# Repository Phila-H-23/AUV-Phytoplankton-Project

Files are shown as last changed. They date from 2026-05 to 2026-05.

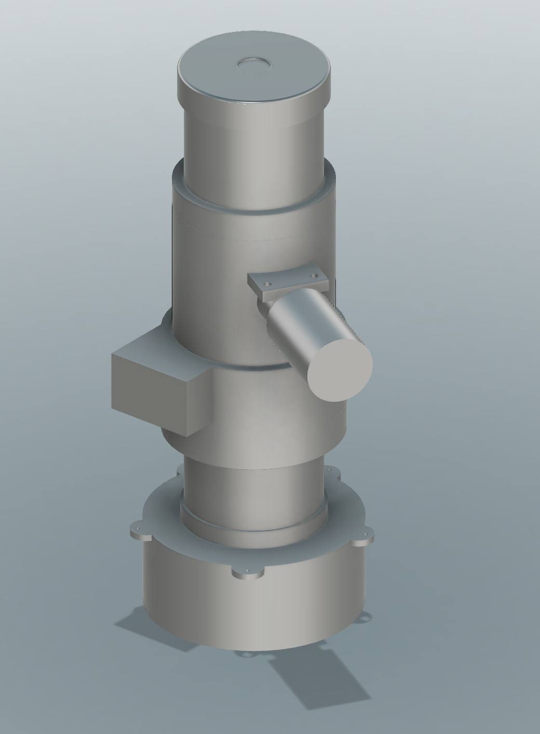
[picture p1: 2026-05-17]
Housing Design/renders/full_sys_design.png

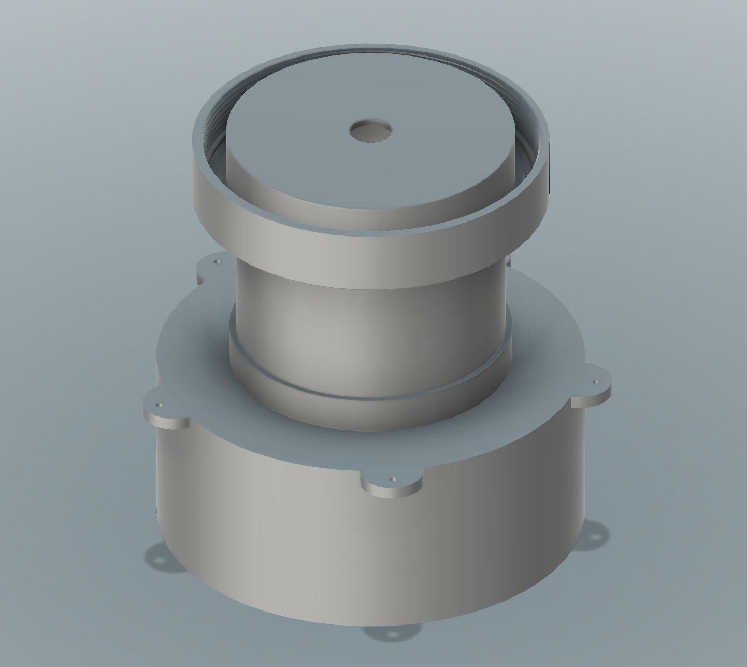
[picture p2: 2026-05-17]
Housing Design/renders/external_cylinder.png

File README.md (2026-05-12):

# AUV-Phytoplankton-project

## EEE4113F Group Project — University of Cape Town

An autonomous underwater vehicle (AUV) designed for vertical water column profiling and phytoplankton concentration measurement. The vehicle uses a buoyancy-driven mechanism to control depth, making it quiet, energy-efficient, and minimally disruptive to the surrounding marine environment.

## Project overview
Phytoplankton play a critical role in marine ecosystems and are sensitive indicators of ocean health. This AUV autonomously profiles the water column, measuring phytoplankton concentration at varying depths without external control or propulsion. By using buoyancy rather than thrusters, the vehicle avoids disturbing the water column during measurement — improving data quality and reducing power consumption.

# Repository structure
```
AUV-Phytoplankton-Project/
│
├── Depth Controller/       # Control system design and firmware
├── Actuator Design/        # Buoyancy actuator design and 3D models
├── Housing Design/         # Pressure housing design and 3D models
└── Power/                  # Power electronics and electrical systems
```

# Subsystems
### 🎛️ Depth controller
The depth control subsystem is responsible for autonomously regulating the vehicle's depth during a dive profile. It processes sensor data and drives the buoyancy actuator to track target depth setpoints.

### ⚙️ Actuator design
The buoyancy actuator controls the vehicle's depth by varying its displaced volume. A syringe mechanism draws in or expels water to make the vehicle sink or rise, with 3D-printed components designed for reliable underwater operation.

### 🏠 Housing design
The pressure housing provides a watertight enclosure for all onboard electronics. It is designed to withstand hydrostatic pressure during dives while remaining compact and manufacturable using available fabrication methods.

### 🔋 Power
The power subsystem is responsible for all electrical power on the vehicle. This includes battery selection and charging, power distribution to all subsystems, motor drive circuitry, voltage regulation for the microcontroller and sensors, and the design of supporting circuits such as switching circuits and protection electronics.

## Getting started
Each subsystem folder contains its own documentation. Refer to the individual folders for design files, source code, and setup instructions specific to each subsystem.

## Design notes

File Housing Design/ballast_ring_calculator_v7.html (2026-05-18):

# Ballast Ring Calculator

EEE4113F // Group 1 // 2026

Float: Ø120 mm · System mass (no ring): ~1,630 g (PLA 15% infill) · sensors included · ID fixed at Ø126 mm

Ring geometry

Inner diameter (ID)126 mm (fixed)

Fits over ext. cylinder OD (120 mm) + 3 mm wall clearance.

Outer diameter (OD)160 mm

Ring wall = (OD − ID) / 2

Ring height h20 mm

Number stacked1

Stack identical rings at the bottom for more mass.

Weight mode

Solid ring Loose hardware Bolts + sand

Material

Corrosion-resistant, seawater-safe. Recommended.

Bolts screwed symmetrically on PCD (midpoint of ID and OD). Count calculated from how many fit.

Hardware material

Bolt/nut size

Rows of bolts (axial)1

PCD: — mm · Bolts/row: — · Total: —
Per bolt: — g · Total mass: — g

Fixed: 1 pack M10×100 bolts (10 bolts, ~720 g) on PCD. Remaining groove filled with sand (ρ = 1,920 kg/m³). Groove height = ring height × rings stacked (set above).

Groove vol: — cm³ · Bolts displace: — cm³
Sand vol: — cm³ · Sand mass: — g
Bolt mass (fixed): 720 g · Total: — g

Zone heights

Top cap + electronicsmm

Sensor + actuator zonemm

External cylindermm

Total height | 528 mm
Float diameter | 120 mm (fixed)
Piston stroke | 164.4 mm
Swept volume | 1,832 mL
Total displacement | 6,865 mL

Piston state

Extended (float) Retracted (sink)

Sensor mass

With sensors Without sensors

ECO: 400g · TRN100: 35g · GNSS: 2.75g = 437.75g

Ring mass

—g

Net buoyancy

—N

CB−CM sep.

—%L

CM from bottom

—mm

Ring volume

—cm³

Wall thickness

—mm

Equilibrium pos.

—mm

Eq. (% stroke)

—%

Water at eq.

—mL

Cross-section — to scale (vertical)

—

Calculations

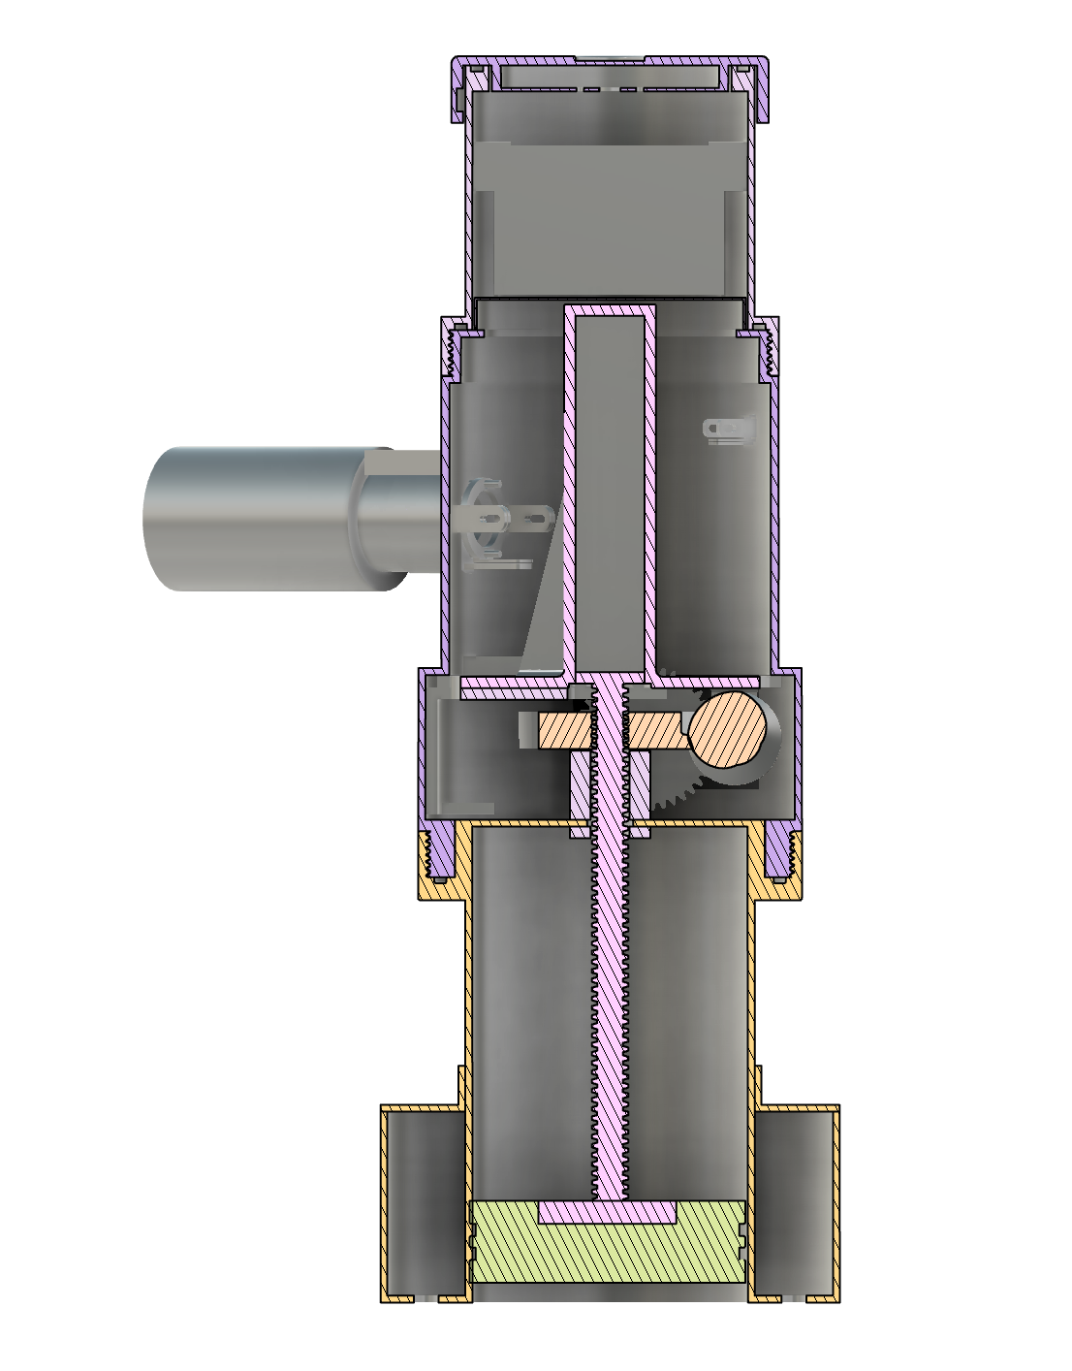
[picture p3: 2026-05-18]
Housing Design/renders/front.png

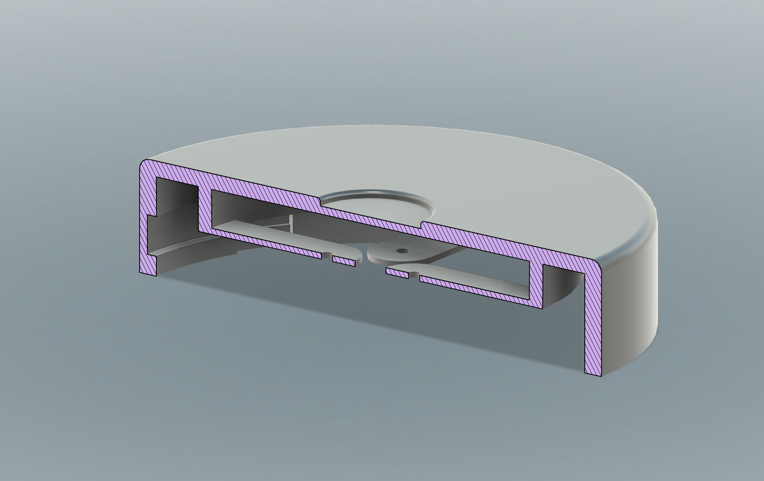
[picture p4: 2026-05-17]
Housing Design/renders/top_cap_section.png

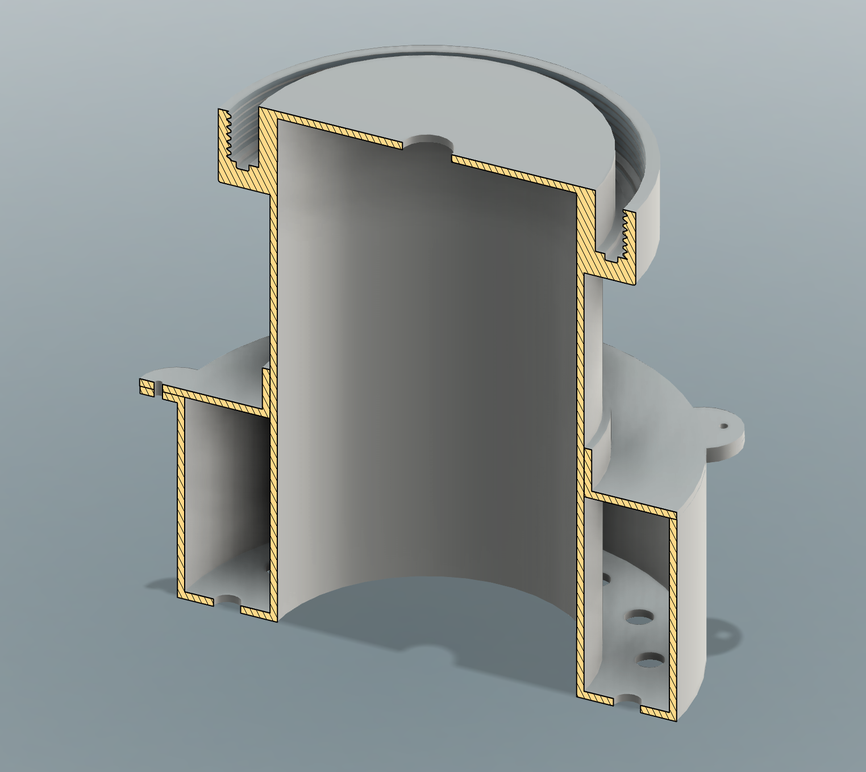
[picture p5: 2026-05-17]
Housing Design/renders/external_cylinder_section.png

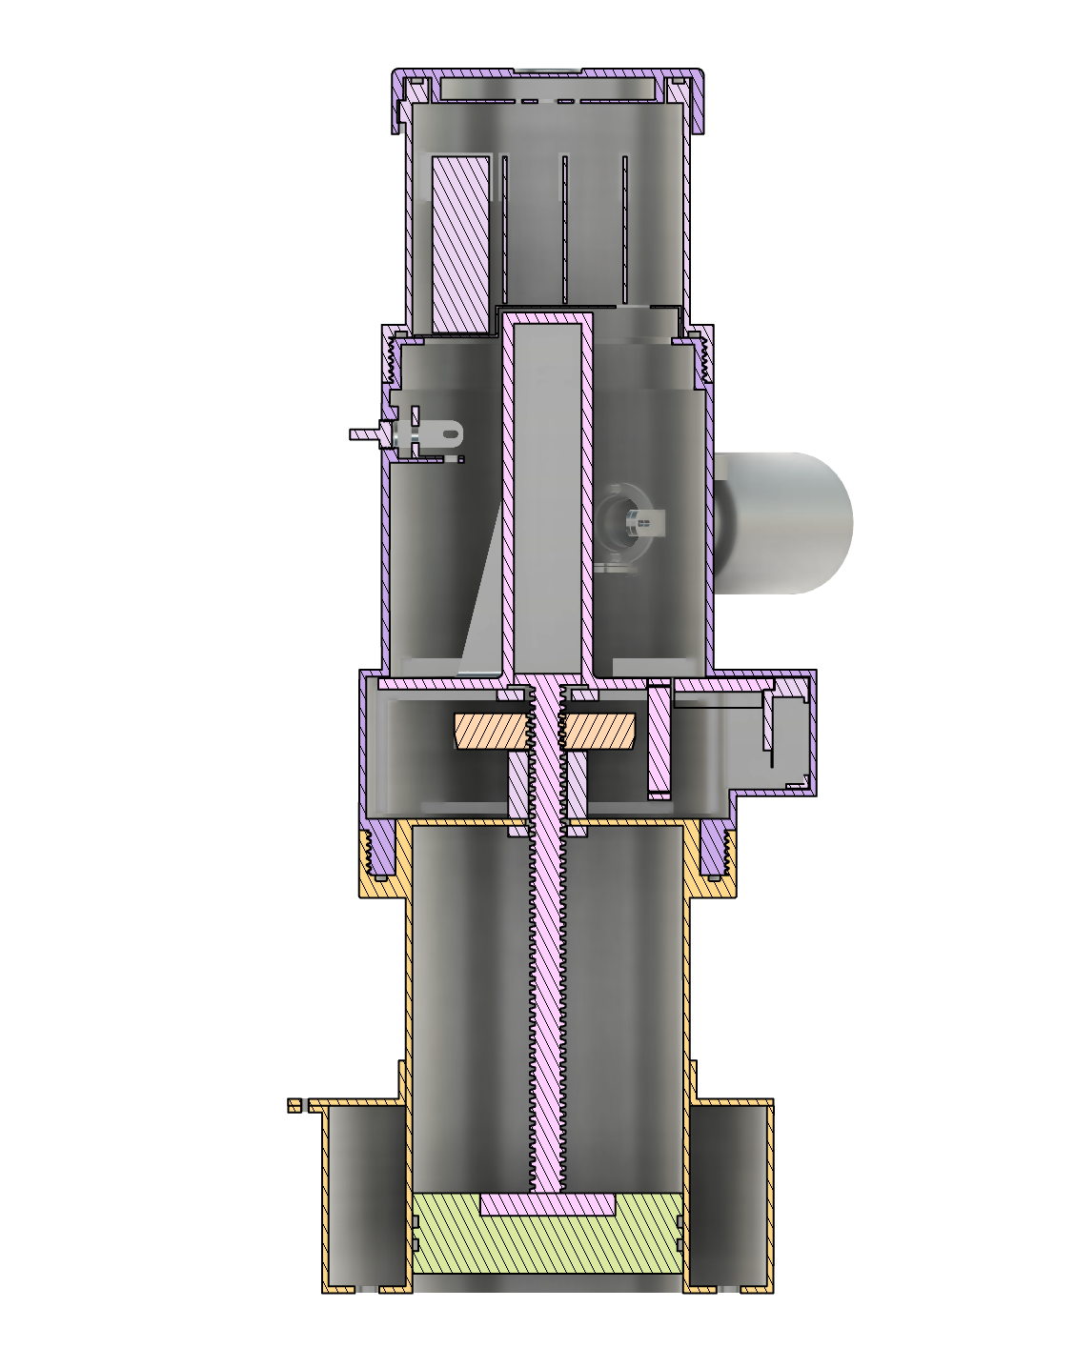
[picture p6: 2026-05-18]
Housing Design/renders/right.png

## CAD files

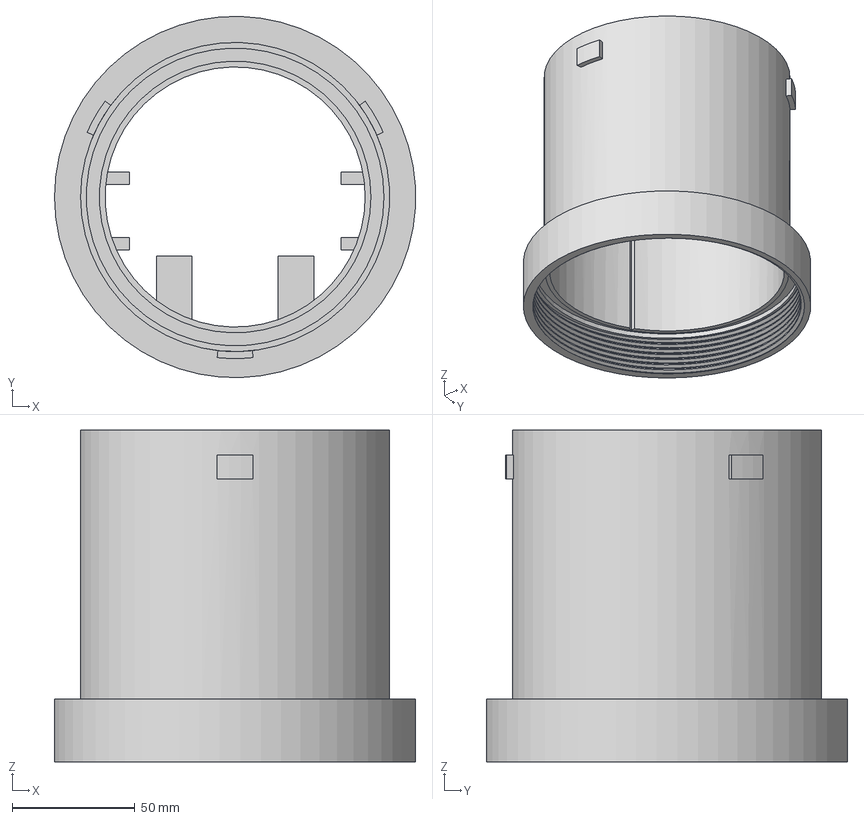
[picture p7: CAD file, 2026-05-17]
Housing Design/system components - step files/electronics tube.step
146.9 x 146.9 x 135.0 mm

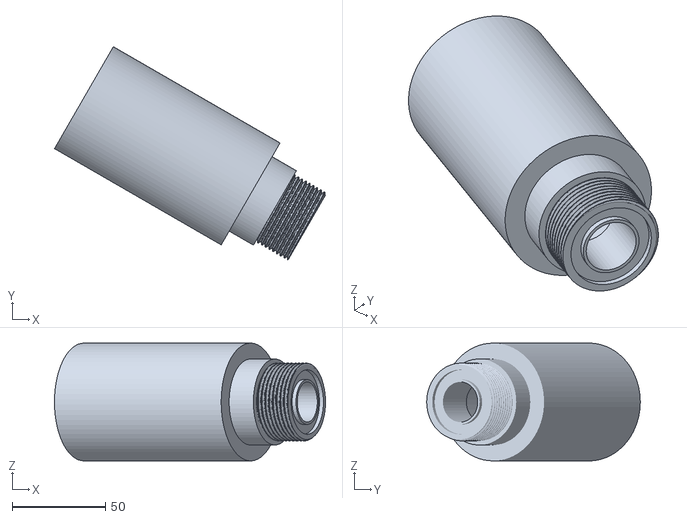
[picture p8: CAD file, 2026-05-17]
Housing Design/system components - stl files/mock eco flntu - model.stl
145.0 x 114.3 x 63.0

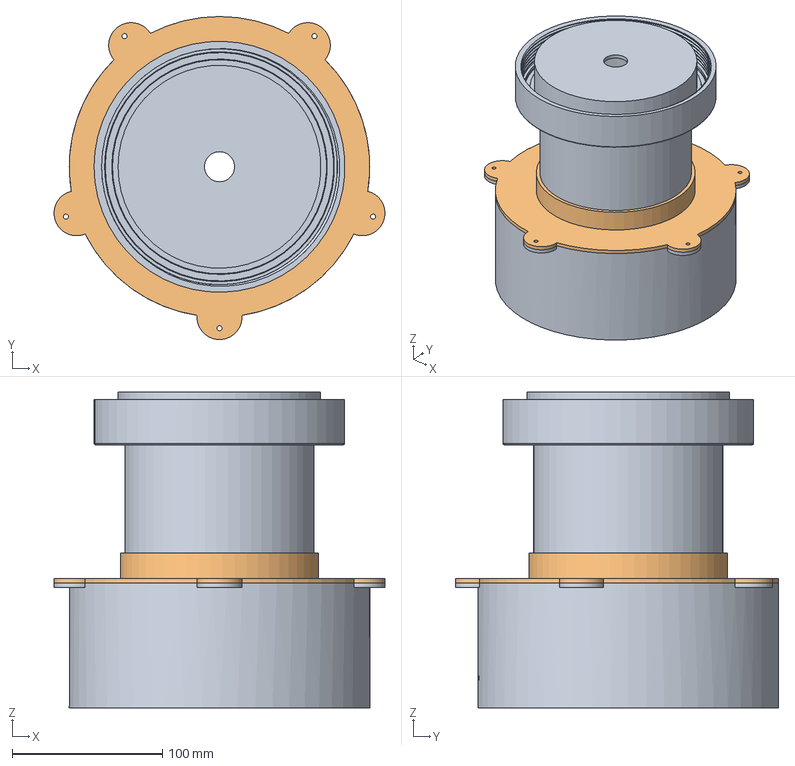
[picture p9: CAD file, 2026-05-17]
Housing Design/system components - step files/external cylinder.step
220.2 x 215.0 x 210.0 mm

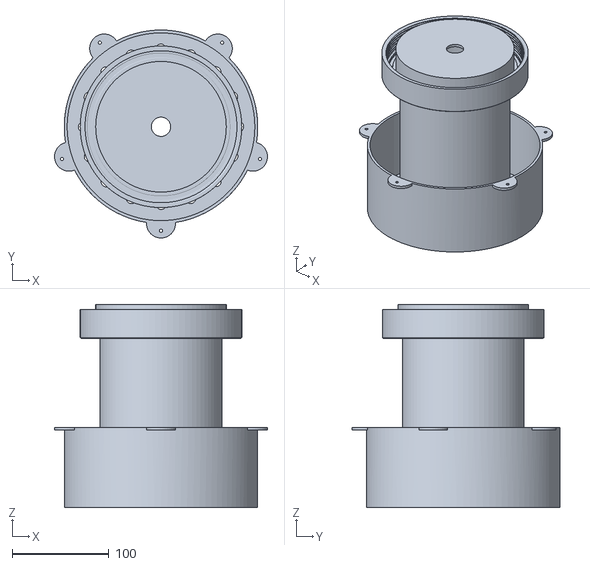
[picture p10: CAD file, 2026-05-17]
Housing Design/system components - stl files/external cylinder - model.stl
220.2 x 214.9 x 210.0

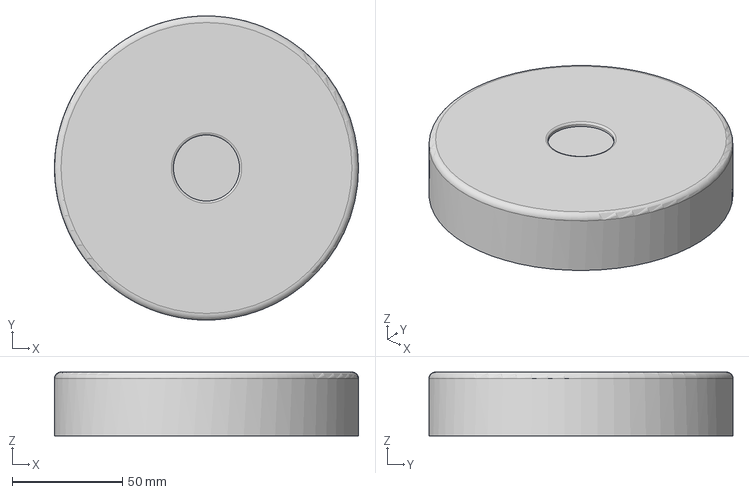
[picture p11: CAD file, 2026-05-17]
Housing Design/system components - step files/top cap.step
138.0 x 138.0 x 29.0 mm

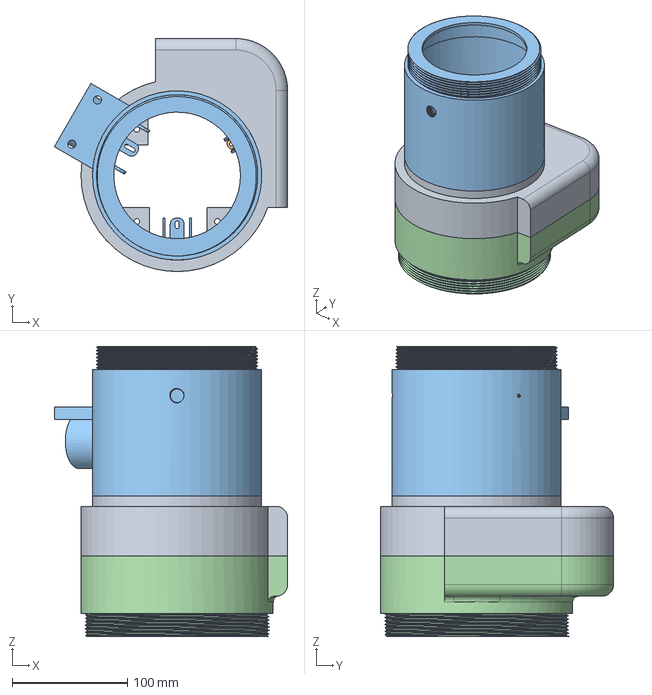
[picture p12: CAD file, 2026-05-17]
Housing Design/system components - step files/sensor-actuator zone.step
202.7 x 202.5 x 252.0 mm

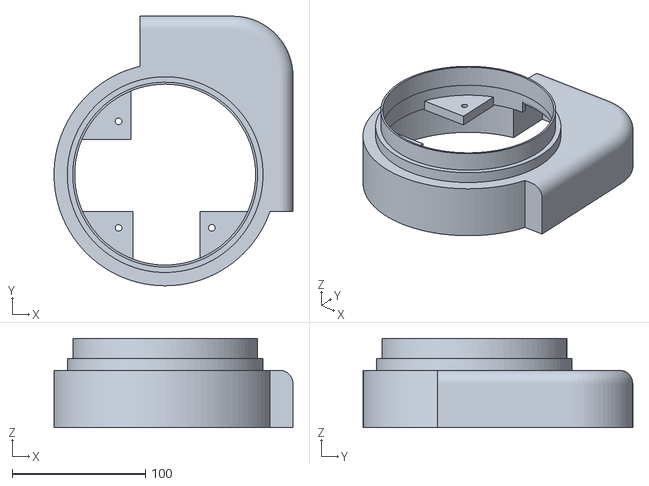
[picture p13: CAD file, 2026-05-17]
Housing Design/system components - stl files/sensor-actuator zone MIDDLE - model.stl
179.5 x 202.5 x 66.9

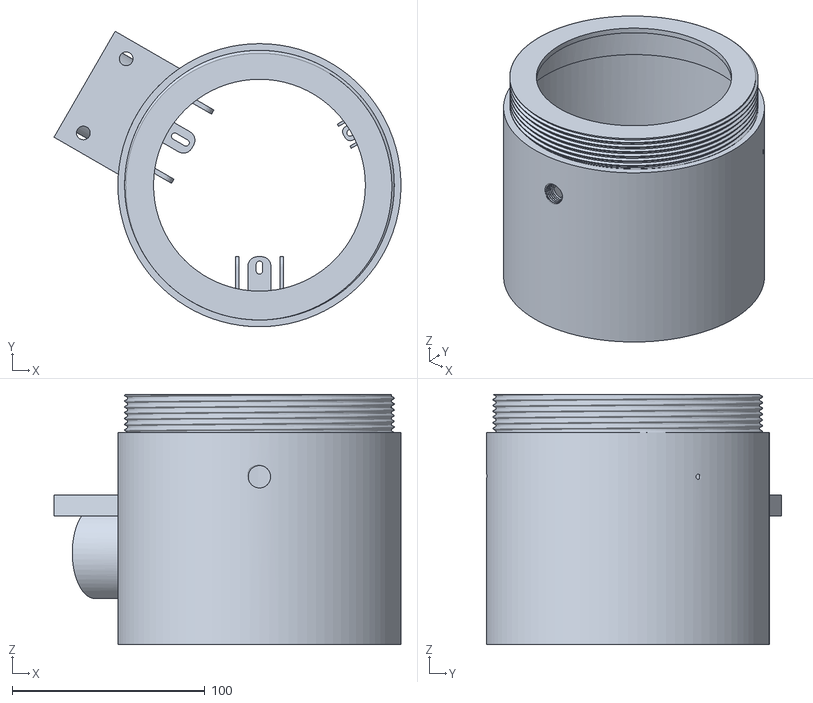
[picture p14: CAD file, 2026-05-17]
Housing Design/system components - stl files/sensor-actuator zone TOP - model.stl
180.2 x 153.4 x 130.0

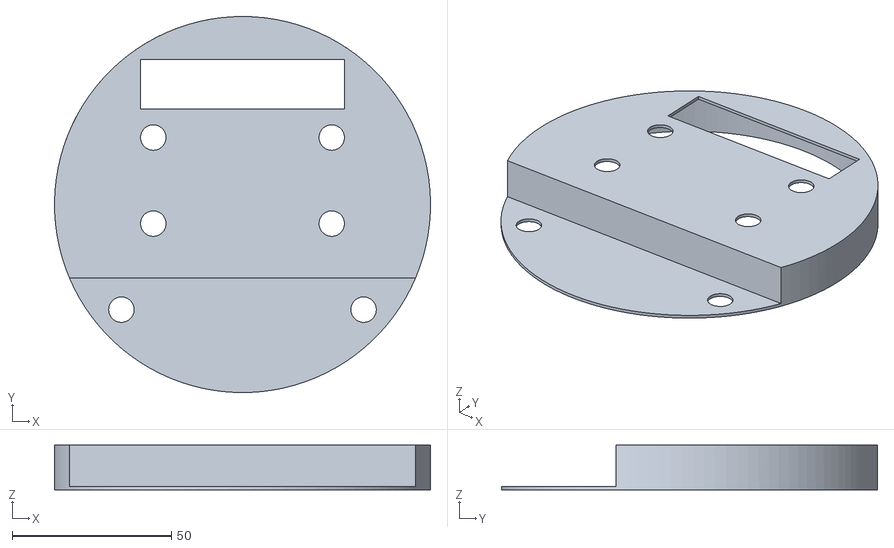
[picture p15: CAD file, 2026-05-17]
Housing Design/system components - stl files/electronics balancer - model.stl
118.0 x 118.0 x 14.0

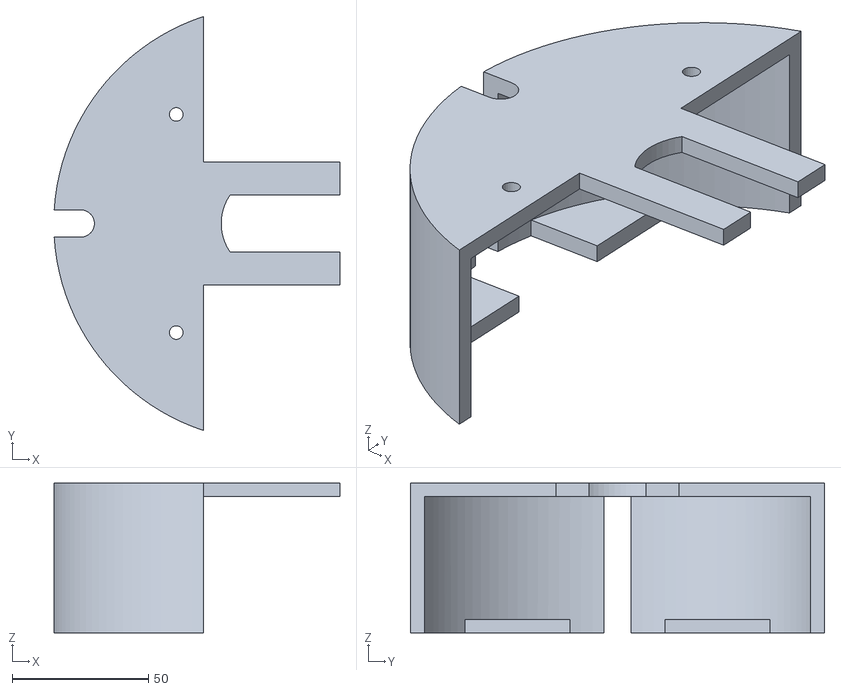
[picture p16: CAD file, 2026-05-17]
Housing Design/system components - stl files/guide cylinder fastener - model.stl
104.8 x 151.8 x 55.0

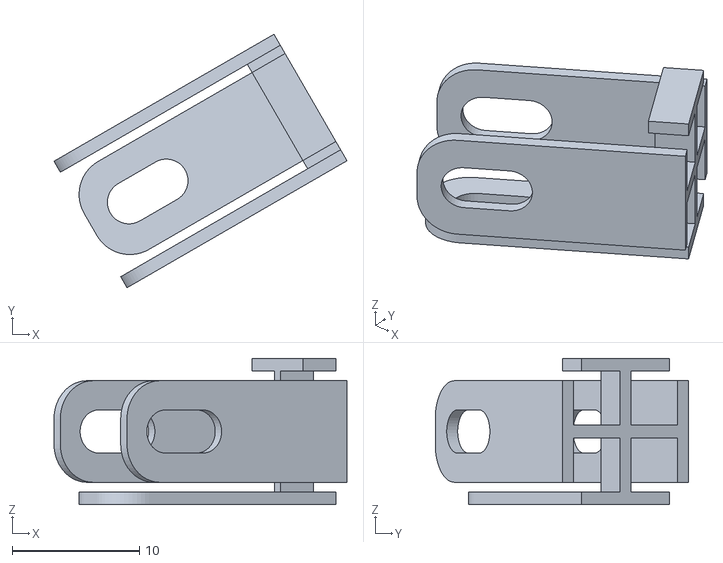
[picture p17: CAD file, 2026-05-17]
Housing Design/system components - stl files/depth sensor fastener - model.stl
23.1 x 20.0 x 11.5

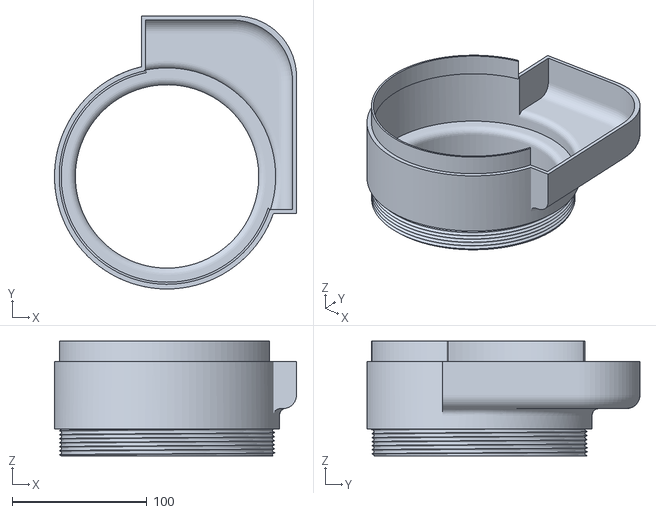
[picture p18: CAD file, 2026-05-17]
Housing Design/system components - stl files/sensor-actuator zone BOTTOM - model.stl
179.5 x 202.5 x 85.0

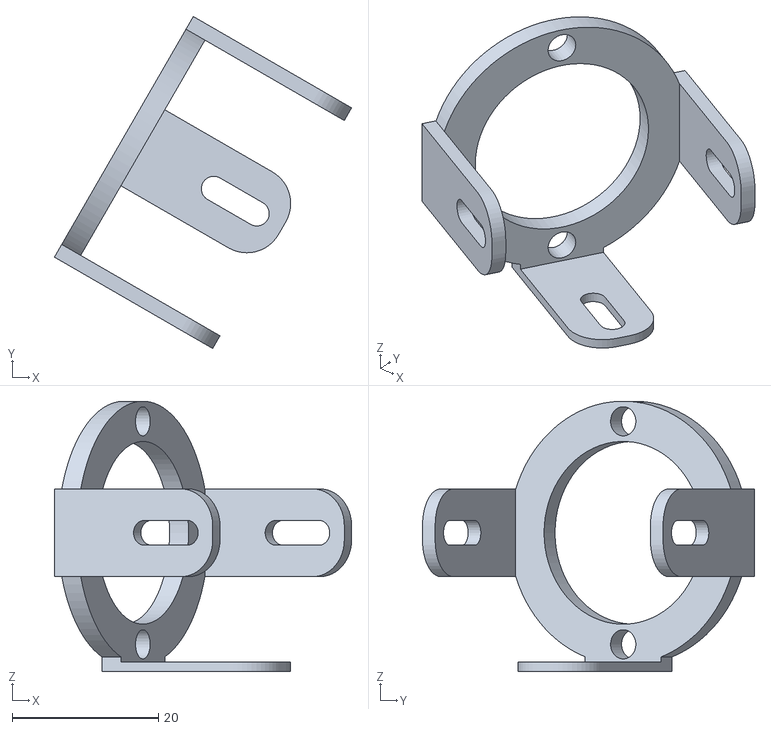
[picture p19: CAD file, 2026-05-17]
Housing Design/system components - stl files/eco flntu fastener - model.stl
40.7 x 45.4 x 37.0

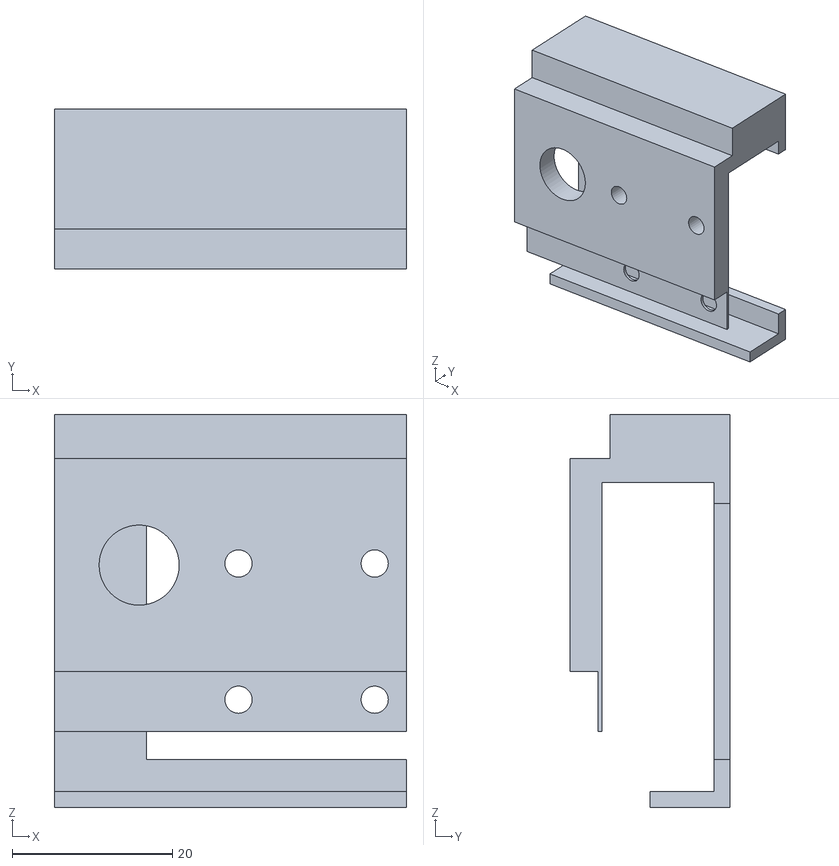
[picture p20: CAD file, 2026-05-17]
Housing Design/system components - stl files/angle sensor mount - model.stl
44.0 x 20.0 x 49.1

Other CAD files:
Housing Design/system components - stl files/electronics tube - model.stl
Housing Design/system components - stl files/service cap - model.stl
Housing Design/system components - stl files/weight lid - model.stl
Housing Design/system components - stl files/temp sensor fastener - model.stl
Actuator Design/Gears.f3d
Actuator Design/Guide_Stand.f3d
Actuator Design/Lead Screw Head.f3d
Actuator Design/Lead Screw.f3d
Actuator Design/Motor.f3d
Actuator Design/Piston head.f3d
Actuator Design/Radial Bearing Stand.f3d
Actuator Design/Thrust Bearing Worm.f3d

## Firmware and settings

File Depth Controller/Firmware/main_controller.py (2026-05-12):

# ================================================================
# main_controller.py
# MicroPython -- Raspberry Pi Pico
# Cascaded depth controller for buoyancy-driven UUV
#
# Architecture:
#   Outer loop: MS5837 depth feedback -> shaft velocity reference
#   Inner loop: AS5600 shaft velocity feedback -> motor voltage
#
# Physical behaviour:
#   Piston retracts (shaft_pos increases) -> water fills chamber
#                                         -> vehicle gets heavier
#                                         -> vehicle sinks (depth increases)
#   Piston extends  (shaft_pos decreases) -> water leaves chamber
#                                         -> vehicle gets lighter
#                                         -> vehicle rises  (depth decreases)
#
# Constraints enforced:
#   1. Stroke limits   -- piston cannot travel beyond 0-16.2cm
#   2. Velocity limit  -- shaft velocity capped at 14.73 mm/s (physical max)
#   3. Current limit   -- voltage clamped to +/-2.142V (3A x Ra) at two points
#   4. Depth fault     -- latching stop if depth exceeds DEPTH_MAX_OP
#   5. Stroke fault    -- latching stop if encoder exceeds stroke limit
#
# Startup sequence (order is critical):
#   1. Ensure piston is fully extended (maximum buoyancy, vehicle at surface)
#   2. Run check_magnet()  -- confirm AS5600 has valid magnet signal
#   3. Run encoder.calibrate() -- set position zero at fully extended position
#   4. Run depth_s.calibrate() -- record atmospheric pressure before water entry
#   5. Set TARGET_DEPTH and run
# ================================================================
 
from machine import I2C, Pin
import time
 
from sensor_interface import AS5600, MS5837
from motor_driver import BTS7960
from parameters import (Ks, Ts, V_SAFE_MAX, V_SAFE_MIN,
                        NUM_INNER, DEN_INNER, K_OUTER, K_D,
                        ALPHA_VEL,ALPHA_DR, STROKE_MAX, STROKE_MIN,
                        MAX_STROKE_VELOCITY, STROKE_EQUILIBRIUM,
                        DEPTH_MIN_OP, DEPTH_MAX_OP)
 
# ================================================================
# HARDWARE INITIALISATION
# I2C bus 0: SDA=GP4 (pin 6), SCL=GP5 (pin 7), 400kHz
# Both AS5600 (0x36) and MS5837 (0x76) share this bus
# ================================================================
i2c     = I2C(0, sda=Pin(4), scl=Pin(5), freq=400_000)
encoder = AS5600(i2c, Ks, ALPHA_VEL)
depth_s = MS5837(i2c, fluid_density=1025.0)    # seawater: 1025, fresh: 1000
motor   = BTS7960(v_supply=12.0)
 
# ================================================================
# STARTUP CALIBRATION SEQUENCE
# ================================================================
print("\n--- Startup sequence ---")
print("Ensure piston is FULLY EXTENDED before continuing")
print("(maximum buoyancy -- vehicle should float at surface)")
 
encoder.check_magnet()     # verify AS5600 magnet signal is valid
encoder.calibrate()        # zero shaft position at fully extended
depth_s.calibrate()        # record surface pressure before water entry
 
print(f"\nEquilibrium stroke position: {STROKE_EQUILIBRIUM*100:.1f} cm")
print(f"Control authority: +/-{STROKE_EQUILIBRIUM*100:.1f} cm from equilibrium")
print("Calibration complete\n")
 
# ================================================================
# MISSION SETPOINT
# Change TARGET_DEPTH to set the desired operating depth [m]
# For first hardware test use a small value (e.g. 0.2m)
# ================================================================
TARGET_DEPTH = 0.2          # m -- START SMALL for first test
 
# ================================================================
# CONTROLLER STATE
# Two samples of memory needed for the second-order difference equation
# Must be reset to zero at startup (or on mission restart)
# ================================================================
e_prev1 = 0.0   # inner loop error: e[k-1]
e_prev2 = 0.0   # inner loop error: e[k-2]
u_prev1 = 0.0   # inner loop output: u[k-1]
u_prev2 = 0.0   # inner loop output: u[k-2]
depth_prev = 0.0    # for derivative term on depth rate
depth_rate_filt  = 0.0   # low-pass filtered depth rate (2 rad/s cutoff)
# ================================================================
# FAULT FLAG
# Latches True on any safety limit violation
# Motor stops and stays stopped until power cycle
# ================================================================
FAULT = False
 
# ================================================================
# CONTROL STEP FUNCTION
# Implements one iteration of the cascaded controller
# Called every Ts=0.005s (200Hz) from the main loop
# ================================================================
def control_step(target_depth, meas_depth, shaft_pos, shaft_vel):
    """
    One 200Hz iteration of the cascaded depth controller.
 
    Outer loop (slow, 1.0 rad/s bandwidth):
        Computes how fast the piston should move based on depth error.
        Positive depth error (too shallow) -> positive shaft_vel_ref (retract)
        Negative depth error (too deep)    -> negative shaft_vel_ref (extend)
 
    Inner loop (fast, 21.5 rad/s bandwidth):
        Tracks the velocity reference from the outer loop.
        Implements the discrete lead-integrator compensator.
        Outputs a voltage command to the motor driver.
 
    Constraints applied (in order):
        1. Stroke limits  -- zero velocity reference at physical endpoints
        2. Velocity limit -- cap shaft velocity to physical maximum
        3. Current limit  -- clamp voltage to +/-V_SAFE_MAX
 
    Args:
        target_depth : float -- desired depth setpoint [m]
        meas_depth   : float -- current depth from MS5837 [m]
        shaft_pos    : float -- current piston position from AS5600 [m]
        shaft_vel    : float -- current piston velocity from AS5600 [m/s]
 
    Returns:
        voltage      : float -- motor voltage command [V]
        shaft_vel_ref: float -- velocity reference sent to inner loop [m/s]
    """
    global e_prev1, e_prev2, u_prev1, u_prev2, depth_prev, depth_rate_filt

    # ---- Depth rate estimate: differentiate then low-pass filter ----
    # Raw differentiation at 200Hz amplifies MS5837 noise severely.
    # ALPHA_DR = exp(-2 * Ts) = 0.9900 gives 2 rad/s cutoff --
    # fast enough to track real depth changes, slow enough to reject noise.
    depth_rate_raw  = (meas_depth - depth_prev) / Ts
    depth_rate_filt = ALPHA_DR * depth_rate_filt \
                    + (1.0 - ALPHA_DR) * depth_rate_raw
    depth_prev      = meas_depth

    # ---- Outer loop: PD on depth ----------------------------
    # K_OUTER = 0.1  proportional -- drives toward target
    # K_D     = 4.3  derivative   -- brakes approach, prevents overshoot
    depth_error   = target_depth - meas_depth
    shaft_vel_ref = K_OUTER * depth_error - K_D * depth_rate_filt

    # ---- Stroke limits --------------------------------------
    if shaft_pos >= STROKE_MAX and shaft_vel_ref > 0:
        shaft_vel_ref = 0.0
    if shaft_pos <= STROKE_MIN and shaft_vel_ref < 0:
        shaft_vel_ref = 0.0

    # ---- Velocity ceiling -----------------------------------
    shaft_vel_ref = max(-MAX_STROKE_VELOCITY,
                        min( MAX_STROKE_VELOCITY, shaft_vel_ref))

    # ---- Inner loop difference equation --------------------
    e_k = shaft_vel_ref - shaft_vel
    u_k = (DEN_INNER[0] * u_prev1
         + DEN_INNER[1] * u_prev2
         + NUM_INNER[0] * e_k
         + NUM_INNER[1] * e_prev1
         + NUM_INNER[2] * e_prev2)

    # ---- Current limit -------------------------------------
    u_k = max(V_SAFE_MIN, min(V_SAFE_MAX, u_k))

    # ---- Shift memory --------------------------------------
    e_prev2 = e_prev1;  e_prev1 = e_k
    u_prev2 = u_prev1;  u_prev1 = u_k
    return u_k, shaft_vel_ref
 
# ================================================================
# MAIN CONTROL LOOP
# ================================================================
print(f"Controller running")
print(f"  Target depth:      {TARGET_DEPTH} m")
print(f"  Max piston vel:    {MAX_STROKE_VELOCITY*1000:.2f} mm/s")
print(f"  Voltage ceiling:   +/-{V_SAFE_MAX:.4f} V")
print(f"  Sample rate:       {1/Ts:.0f} Hz")
print(f"  Depth fault limit: {DEPTH_MAX_OP} m")
print()
 
loop_count = 0
 
try:
    while not FAULT:
        t0 = time.ticks_ms()
 
        # ---- Read sensors -----------------------------------
        meas_depth = depth_s.read_depth()       # [m] from MS5837
        shaft_pos  = encoder.read_position()    # [m] from AS5600
        shaft_vel  = encoder.read_velocity(Ts)  # [m/s] differentiated + filtered
 
        # ---- Safety fault checks (latching) -----------------
        # Depth fault: vehicle has gone too deep
        if meas_depth > DEPTH_MAX_OP:
            print(f"FAULT: depth {meas_depth:.3f}m exceeds limit {DEPTH_MAX_OP}m")
            FAULT = True
            break
 
        # Stroke fault: encoder reading beyond physical travel
        # 5% tolerance accounts for sensor noise near the endpoint
        if shaft_pos > STROKE_MAX * 1.05:
            print(f"FAULT: shaft {shaft_pos*100:.2f}cm exceeds stroke {STROKE_MAX*100:.1f}cm")
            FAULT = True
            break
 
        # ---- Run cascaded controller ------------------------
        voltage, shaft_vel_ref = control_step(
            TARGET_DEPTH, meas_depth, shaft_pos, shaft_vel)
 
        # ---- Drive motor ------------------------------------
        motor.set_voltage(voltage)
 
        # ---- Log every 10 loops (20Hz printout) -------------
        if loop_count % 10 == 0:
            depth_err  = TARGET_DEPTH - meas_depth
            stroke_pct = (shaft_pos / STROKE_MAX) * 100
 
            # Show direction the controller is commanding
            if shaft_vel_ref > 0.0001:
                cmd_dir = "SINK "
            elif shaft_vel_ref < -0.0001:
                cmd_dir = "RISE "
            else:
                cmd_dir = "HOLD "
 
            print(f"depth:{meas_depth:.3f}m  "
                  f"err:{depth_err:+.3f}m  "
                  f"stroke:{stroke_pct:.1f}%  "
                  f"cmd:{cmd_dir}  "
                  f"vel:{shaft_vel*1000:.3f}mm/s  "
                  f"u:{voltage:.4f}V")
 
        loop_count += 1
 
        # ---- Timing: enforce exactly 200Hz ------------------
        # ticks_diff handles the millisecond counter rollover correctly
        elapsed = time.ticks_diff(time.ticks_ms(), t0)
        delay   = int(Ts * 1000) - elapsed      # remaining ms in this period
        if delay > 0:
            time.sleep_ms(delay)
 
except KeyboardInterrupt:
    print("\nStopped by user (Ctrl+C)")
 
finally:
    # Always executed -- ensures motor stops even if an exception occurs
    motor.close()
    if FAULT:
        print("System halted -- FAULT latched")
        print("Resolve the fault condition then power cycle to restart")
 

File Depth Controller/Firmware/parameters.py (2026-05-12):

# parameters.py — FINAL VERIFIED DESIGN
# Lead angle: 10°  |  Sample rate: 200Hz  |  Depth range: 0-2m
import math

# ================================================================
# MOTOR PARAMETERS
# ================================================================
p_rated      = 19.68
max_torque   = 0.0105
omega_rated  = 22356 * (2 * math.pi / 60)
I_rated      = 5.25
Ra           = p_rated / I_rated**2
Kt           = max_torque / I_rated
Ke           = Kt
J            = 5e-6
b_visc       = max_torque / omega_rated

# ================================================================
# SCREW GEOMETRY — final verified values
# Lead angle: 10°, Diameter: 25mm
# ================================================================
LEAD_ANGLE_DEG = 10.0
SCREW_DIAMETER = 0.025
Lead = math.pi * SCREW_DIAMETER * math.tan(
           math.radians(LEAD_ANGLE_DEG))    # 0.01385 m/rev
Ks   = Lead / (2 * math.pi)                # 0.002204 m/rad

# ================================================================
# PHYSICAL STROKE CONSTRAINTS
# ================================================================
STROKE_MAX = 0.162      # m — fully retracted (max depth)
STROKE_MIN = 0.0        # m — fully extended  (surface)

# Equilibrium: assumed at stroke midpoint
# Symmetric control authority: 0.081m to sink, 0.081m to rise
# Verify and update after water test
STROKE_EQUILIBRIUM = STROKE_MAX / 2    # = 0.081 m

# ================================================================
# DEPTH OPERATING RANGE
# ================================================================
DEPTH_MIN_OP = 0.0      # m — surface
DEPTH_MAX_OP = 2.0      # m — maximum operating depth

# Sign convention:
# Piston RETRACTS (shaft_pos ↑) → vehicle SINKS   (depth ↑)
# Piston EXTENDS  (shaft_pos ↓) → vehicle RISES   (depth ↓)

# ================================================================
# VELOCITY LIMITS
# ================================================================
# Worst case measured: 11s for full stroke at 3m depth
# Conservative ceiling — real velocity at 2m will be slightly faster
MAX_STROKE_VELOCITY = STROKE_MAX / 11.0     # = 0.01473 m/s

# ================================================================
# L298N CURRENT LIMIT
# ================================================================
I_LIMIT    = 3.0
V_SAFE_MAX = I_LIMIT * Ra               # = 2.142 V
V_SAFE_MIN = -V_SAFE_MAX                # = -2.142 V

# ================================================================
# CONTROL LOOP TIMING
# ================================================================
# Inner loop BW = 21.53 rad/s
# 200Hz → 1256.6 rad/s sample rate >> 10× BW requirement
# Discrete inner PM = 58.42° — 13.42° above 45° minimum
Ts = 0.005      # 200 Hz

# ================================================================
# DISCRETE CONTROLLER COEFFICIENTS
# Verified: MATLAB c2d Tustin at 200Hz, lead angle 10°
#
# Difference equation (inner loop):
# u[k] = DEN[0]*u[k-1] + DEN[1]*u[k-2]
#       + NUM[0]*e[k]   + NUM[1]*e[k-1] + NUM[2]*e[k-2]
# ================================================================
NUM_INNER = [ 2.104167,  0.041667, -2.062500]
DEN_INNER = [ 1.777778, -0.777778]
K_OUTER   = 0.1 # tuned via simulation
K_D = 4.3 # derivative damping on depth rate

# ================================================================
# VELOCITY FILTER
# Cutoff: 20 rad/s, recalculated for 200Hz sample rate
# ================================================================
ALPHA_VEL = math.exp(-20.0 * Ts)       # = 0.9048
ALPHA_DR  = math.exp(-2.0  * Ts)       # = 0.9900  depth rate filter     (2 rad/s)
# ================================================================
# STARTUP DIAGNOSTIC
# ================================================================
print("=" * 52)
print("SYSTEM PARAMETERS — FINAL VERIFIED DESIGN")
print("=" * 52)
print(f"Lead angle:          {LEAD_ANGLE_DEG}°")
print(f"Screw lead:          {Lead*1000:.3f} mm/rev")
print(f"Ks:                  {Ks:.6f} m/rad")
print(f"Stroke:              {STROKE_MAX*100:.1f} cm")
print(f"Equilibrium:         {STROKE_EQUILIBRIUM*100:.1f} cm")
print(f"Voltage ceiling:     ±{V_SAFE_MAX:.4f} V  (2A × Ra)")
print(f"Max piston vel:      {MAX_STROKE_VELOCITY*1000:.2f} mm/s")
print(f"Sample rate:         {1/Ts:.0f} Hz")
print(f"Inner PM (discrete): 58.42°")
print(f"Outer PM (discrete): 89.90°")
print(f"  K_outer:              {K_OUTER}")
print(f"  K_D (depth rate):     {K_D}")
print(f"Velocity filter α:   {ALPHA_VEL:.4f}")
print("=" * 52)

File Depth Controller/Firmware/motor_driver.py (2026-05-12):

# ================================================================
# motor_driver.py
# MicroPython -- Raspberry Pi Pico
# BTS7960 43A H-bridge motor driver
#
# Wiring:
#   RPWM -> GP18  (forward PWM  -- hardware PWM channel 0)
#   LPWM -> GP19  (reverse PWM  -- hardware PWM channel 1)
#   R_EN -> GP17  (right enable -- drive HIGH to enable)
#   L_EN -> GP16  (left enable  -- drive HIGH to enable)
#   VCC  -> 5V    (logic supply for driver board)
#   GND  -> GND
#   B+   -> motor power supply positive (your battery/supply)
#   B-   -> motor power supply negative
#   M+   -> motor terminal A
#   M-   -> motor terminal B
#
# BTS7960 control logic:
#   RPWM has duty cycle, LPWM=0 -> forward (piston retracts -> sinks)
#   LPWM has duty cycle, RPWM=0 -> reverse (piston extends  -> rises)
#   Both zero                   -> coast stop
#   Both 100%                   -> active brake
#
# Current limit: BTS7960 rated 43A, externally limited to 3A
# Voltage ceiling: V_SAFE_MAX = I_LIMIT x Ra = 3A x 0.714 = 2.142V
# This means max duty cycle = V_SAFE_MAX / V_SUPPLY x 100 = ~17.9%
# ================================================================
 
from machine import Pin, PWM
from parameters import V_SAFE_MAX, V_SAFE_MIN
 
PIN_RPWM = 18    # GP18 -- forward PWM
PIN_LPWM = 19    # GP19 -- reverse PWM
PIN_R_EN = 17    # GP17 -- right side enable
PIN_L_EN = 16    # GP16 -- left side enable
PWM_FREQ = 20000 # 20kHz -- above audible range, within BTS7960 capability
 
class BTS7960:
    def __init__(self, v_supply=12.0):
        """
        v_supply : float -- actual supply voltage to motor [V]
                   Measure at B+ and B- terminals with a multimeter.
                   Used to scale voltage command to PWM duty cycle.
 
        Note on duty cycle:
            V_SAFE_MAX = 2.142V, v_supply = 12V
            Max duty cycle = 2.142 / 12 x 100 = 17.9%
            This is intentional -- enforces the 3A current limit.
            The BTS7960 can handle far more but the motor and
            external current limit setting constrain it to 3A.
        """
        self.v_supply = v_supply
 
        # Enable pins -- both must be HIGH to enable the H-bridge
        # Drive immediately so motor is ready as soon as object is created
        self.r_en = Pin(PIN_R_EN, Pin.OUT, value=1)
        self.l_en = Pin(PIN_L_EN, Pin.OUT, value=1)
 
        # PWM channels -- duty_u16 range: 0 (0%) to 65535 (100%)
        self.rpwm = PWM(Pin(PIN_RPWM))
        self.lpwm = PWM(Pin(PIN_LPWM))
        self.rpwm.freq(PWM_FREQ)
        self.lpwm.freq(PWM_FREQ)
 
        # Start with both channels at zero -- motor stopped
        self.rpwm.duty_u16(0)
        self.lpwm.duty_u16(0)
 
        max_duty_pct = (V_SAFE_MAX / v_supply) * 100
        print(f"BTS7960 ready")
        print(f"  Supply voltage:  {v_supply}V")
        print(f"  Voltage ceiling: +/-{V_SAFE_MAX:.4f}V  (3A x Ra)")
        print(f"  Max duty cycle:  {max_duty_pct:.1f}%")
        print(f"  PWM frequency:   {PWM_FREQ}Hz")
 
    def set_voltage(self, v_cmd):
        """
        Apply a voltage command from the controller to the motor.
 
        Conversion: v_cmd [V] -> PWM duty cycle on RPWM or LPWM
 
        v_cmd is clamped to +/-V_SAFE_MAX before conversion.
        This is a second enforcement of the current limit
        (control_step() also clamps, giving two layers of protection).
 
        Positive v_cmd -> RPWM active, LPWM=0 -> piston retracts -> sinks
        Negative v_cmd -> LPWM active, RPWM=0 -> piston extends  -> rises
        Zero v_cmd     -> both zero -> coast stop
 
        Args:
            v_cmd : float -- motor voltage command [V] from control_step()
        """
        # Hard clamp -- current limit enforcement (second layer)
        v_cmd = max(V_SAFE_MIN, min(V_SAFE_MAX, v_cmd))
 
        # Scale to 16-bit duty: 0-65535 represents 0%-100% of supply voltage
        duty = int(abs(v_cmd) / self.v_supply * 65535)
 
        if v_cmd > 0:
            # Forward: retract piston, vehicle sinks, depth increases
            self.rpwm.duty_u16(duty)
            self.lpwm.duty_u16(0)
        elif v_cmd < 0:
            # Reverse: extend piston, vehicle rises, depth decreases
            self.rpwm.duty_u16(0)
            self.lpwm.duty_u16(duty)
        else:
            # Zero command -- coast to stop
            self.rpwm.duty_u16(0)
            self.lpwm.duty_u16(0)
 
    def stop(self):
        """
        Coast stop -- remove PWM signals, motor decelerates freely.
        Call on controlled shutdown or between missions.
        """
        self.rpwm.duty_u16(0)
        self.lpwm.duty_u16(0)
        print("BTS7960: motor stopped (coast)")
 
    def brake(self):
        """
        Active brake -- both channels driven simultaneously.
        Shorts the motor terminals through the H-bridge,
        creating a braking torque. Stops faster than coast.
        Use for precise position holding if needed.
        """
        self.rpwm.duty_u16(65535)
        self.lpwm.duty_u16(65535)
 
    def close(self):
        """
        Safe shutdown -- stop motor and disable the H-bridge.
        Call in the finally block of main_controller.py to ensure
        motor always stops even if an exception occurs.
        """
        self.stop()
        self.r_en.value(0)
        self.l_en.value(0)
        print("BTS7960: disabled")

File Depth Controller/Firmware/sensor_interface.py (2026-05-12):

# ================================================================
# sensor_interface.py
# MicroPython -- Raspberry Pi Pico
#
# AS5600 magnetic angle sensor  -- inner loop (shaft velocity)
#   I2C address : 0x36 (fixed, cannot change)
#   Measures shaft rotation -> linear piston position and velocity
#
# MS5837-30BA pressure sensor   -- outer loop (water depth)
#   I2C address : 0x76 (fixed, cannot change)
#   Measures absolute pressure -> depth below surface
#
# Wiring (both sensors share I2C bus 0):
#   SDA -> GP4 (pin 6)
#   SCL -> GP5 (pin 7)
#   VCC -> 3.3V (pin 36)  -- do NOT connect to 5V
#   GND -> GND (pin 38)
#   AS5600 PS pin -> 3.3V  -- selects I2C mode (CRITICAL -- float = broken)
# ================================================================
 
from machine import I2C, Pin
import time
import math
 
# ================================================================
# AS5600 -- 12-bit magnetic angle sensor
# ================================================================
AS5600_ADDR      = 0x36
AS5600_ANGLE_REG = 0x0C   # filtered angle output (12-bit, two bytes)
AS5600_STATUS    = 0x0B   # magnet detection status
 
class AS5600:
    def __init__(self, i2c, Ks, alpha_vel, counts_per_rev=4096):
        """
        i2c           : machine.I2C object
        Ks            : screw gain [m/rad] from parameters.py
        alpha_vel     : velocity low-pass filter coefficient from parameters.py
        counts_per_rev: 4096 (12-bit = 0 to 4095 counts per revolution)
 
        Coordinate convention:
            shaft_pos = 0.000m -> piston fully extended (surface, max buoyancy)
            shaft_pos = 0.162m -> piston fully retracted (max depth, min buoyancy)
            Positive shaft velocity -> retracting -> vehicle sinking
            Negative shaft velocity -> extending  -> vehicle rising
        """
        self.i2c   = i2c
        self.Ks    = Ks
        self.CPR   = counts_per_rev
        self.ALPHA = alpha_vel      # 0.9048 at 200Hz for 20 rad/s cutoff
 
        # Multi-turn tracking (AS5600 only outputs 0-4095 per revolution)
        self._count_prev  = None    # last raw count reading
        self._turn_offset = 0       # cumulative full-turn correction in counts
        self._zero_count  = 0       # raw count at calibration zero
 
        # Velocity estimation state
        self._pos_prev = 0.0        # position from previous loop iteration [m]
        self._vel_f    = 0.0        # filtered velocity output [m/s]
 
    def check_magnet(self):
        """
        Verify magnet is correctly positioned over the AS5600.
        Call once at startup before any other AS5600 methods.
 
        Status register bits:
            MD (bit 5) = 1 -> magnet detected correctly
            ML (bit 4) = 1 -> magnet too weak  -> move magnet closer
            MH (bit 3) = 1 -> magnet too strong -> move magnet further away
 
        Raises RuntimeError if no magnet is detected.
        """
        status = self.i2c.readfrom_mem(AS5600_ADDR, AS5600_STATUS, 1)[0]
        md = (status >> 5) & 1
        ml = (status >> 4) & 1
        mh = (status >> 3) & 1
        if not md:
            raise RuntimeError("AS5600: no magnet detected -- check placement and wiring")
        if ml:
            print("AS5600 WARNING: magnet too weak -- move magnet closer to sensor")
        if mh:
            print("AS5600 WARNING: magnet too strong -- move magnet further from sensor")
        print("AS5600: magnet detected OK")
        return md
 
    def _read_raw_count(self):
        """
        Read 12-bit angle from registers 0x0C (high byte) and 0x0D (low byte).
        Upper 4 bits of the high byte are unused and masked to zero.
        Returns integer 0-4095 representing current shaft angle.
        """
        data = self.i2c.readfrom_mem(AS5600_ADDR, AS5600_ANGLE_REG, 2)
        return ((data[0] & 0x0F) << 8) | data[1]
 
    def calibrate(self):
        """
        Set the position zero reference.
        Call with piston FULLY EXTENDED (maximum buoyancy, vehicle at surface).
        This maps shaft_pos = 0.000m to that physical position.
 
        Must be called before read_position() or read_velocity().
        Resets all internal state to zero.
        """
        self._zero_count  = self._read_raw_count()
        self._count_prev  = self._zero_count
        self._turn_offset = 0
        self._pos_prev    = 0.0
        self._vel_f       = 0.0
        print(f"AS5600: zeroed at raw count {self._zero_count}")
 
    def read_position(self):
        """
        Returns cumulative linear piston position [m] from the zero reference.
        Handles multi-turn shaft rollover automatically.
 
        Rollover detection logic:
            AS5600 wraps from 4095->0 (forward) or 0->4095 (reverse).
            If two consecutive readings differ by more than 2048 counts
            (half a revolution), a rollover has occurred.
            Direction of the jump determines whether to add or subtract
            one full revolution worth of counts.
 
        Returns:
            0.000m = piston fully extended  (surface, max buoyancy)
            0.162m = piston fully retracted (maximum depth, min buoyancy)
        """
        raw = self._read_raw_count()
 
        if self._count_prev is not None:
            delta = raw - self._count_prev
            if delta >  self.CPR // 2:
                # Jumped backwards past zero count -- rolled one revolution backward
                self._turn_offset -= self.CPR
            elif delta < -self.CPR // 2:
                # Jumped forwards past 4095 -- rolled one revolution forward
                self._turn_offset += self.CPR
 
        self._count_prev = raw
 
        # Total counts accumulated since calibration zero
        cumulative = (raw + self._turn_offset) - self._zero_count
 
        # Convert: counts -> radians -> linear metres
        angle_rad = (cumulative / self.CPR) * 2 * math.pi
        return angle_rad * self.Ks
 
    def read_velocity(self, Ts):
        """
        Returns filtered linear piston velocity [m/s].
        Differentiates consecutive position readings, then applies
        an exponential low-pass filter to reduce encoder noise.
 
        Must be called exactly once per control loop at interval Ts.
        Calling more or less frequently will give incorrect velocity.
 
        Positive = retracting = sinking
        Negative = extending  = rising
 
        Args:
            Ts : float -- control loop sample period [s] from parameters.py
        """
        pos     = self.read_position()
        vel_raw = (pos - self._pos_prev) / Ts
 
        # Exponential low-pass: alpha=0.9048 at 200Hz gives 20 rad/s cutoff
        # Suppresses high-frequency encoder quantisation noise
        self._vel_f    = self.ALPHA * self._vel_f + (1.0 - self.ALPHA) * vel_raw
        self._pos_prev = pos
        return self._vel_f
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

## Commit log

2026-05-12 added placeholder files for 3D model folders
    - created txt files in actuator and housing folders so they appear on github
    - can be deleted after something else is added
2026-05-12 power folder created
2026-05-15 Update hardware_test.py
    fixed the motor driver test as it wasn't working
    [hardware_test.py]
2026-05-16 Add files via upload
    Added all Final CAD Files to the Repo
    [Gears.f3d, Guide_Stand.f3d, Lead Screw Head.f3d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]
2026-05-16 Read me providing general tips for the assembly process
2026-05-16 Added ReadMe with general assembly tips and breakdown of each file
2026-05-17 Uploaded component STL files, fusion file of final design, interactive weight calculator
    [angle sensor mount - model.stl, depth sensor fastener - model.stl, eco flntu fastener - model.stl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]
2026-05-17 Added STEP files of major components for simulations
    [angle sensor mount - model.stl, depth sensor fastener - model.stl, eco flntu fastener - model.stl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]
